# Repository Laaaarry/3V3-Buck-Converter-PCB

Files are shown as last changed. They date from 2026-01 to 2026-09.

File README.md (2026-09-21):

# 3V3 Buck Converter Project

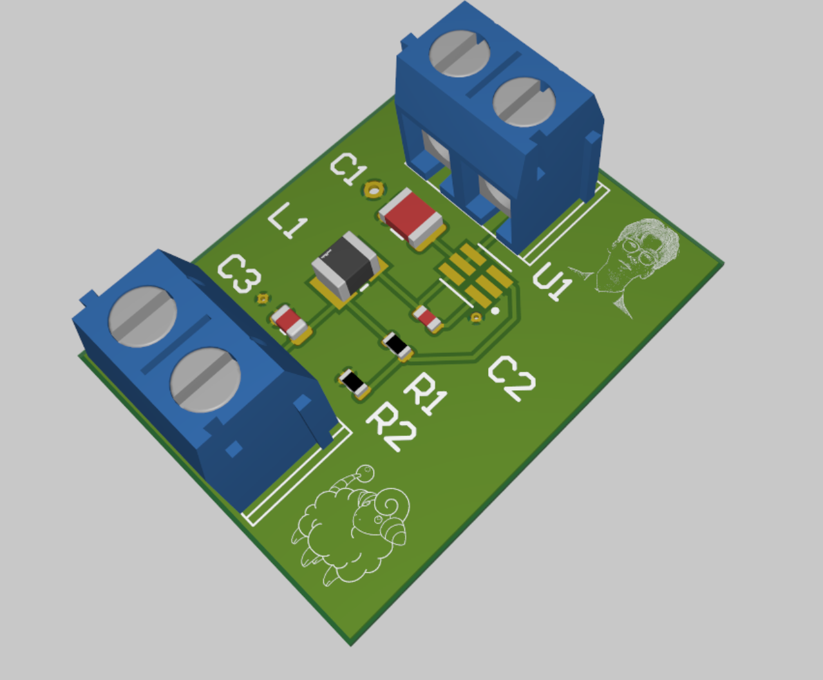
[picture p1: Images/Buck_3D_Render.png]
Board Render


Links:

**[Schematic + layout PDF](FAB-Lawrence_BuckConverter-A.1/Job1.PDF)**

**[BOM](FAB-Lawrence_BuckConverter-A.1/BOM/Lawrence_BuckConverter_BOM.xlsx)**

**[Fab package](FAB-Lawrence_BuckConverter-A.1/)**

## Overview
A 3V3 buck converter designed to take a higher voltage input and output 3.3 volts, with an output ripple voltage of under 100mV. 2-layer PCB with 9 components.
## Key Images

### Schematic Overview
Schematic of the 3V3 Buck converter. Uses a LMR50410 switcher.
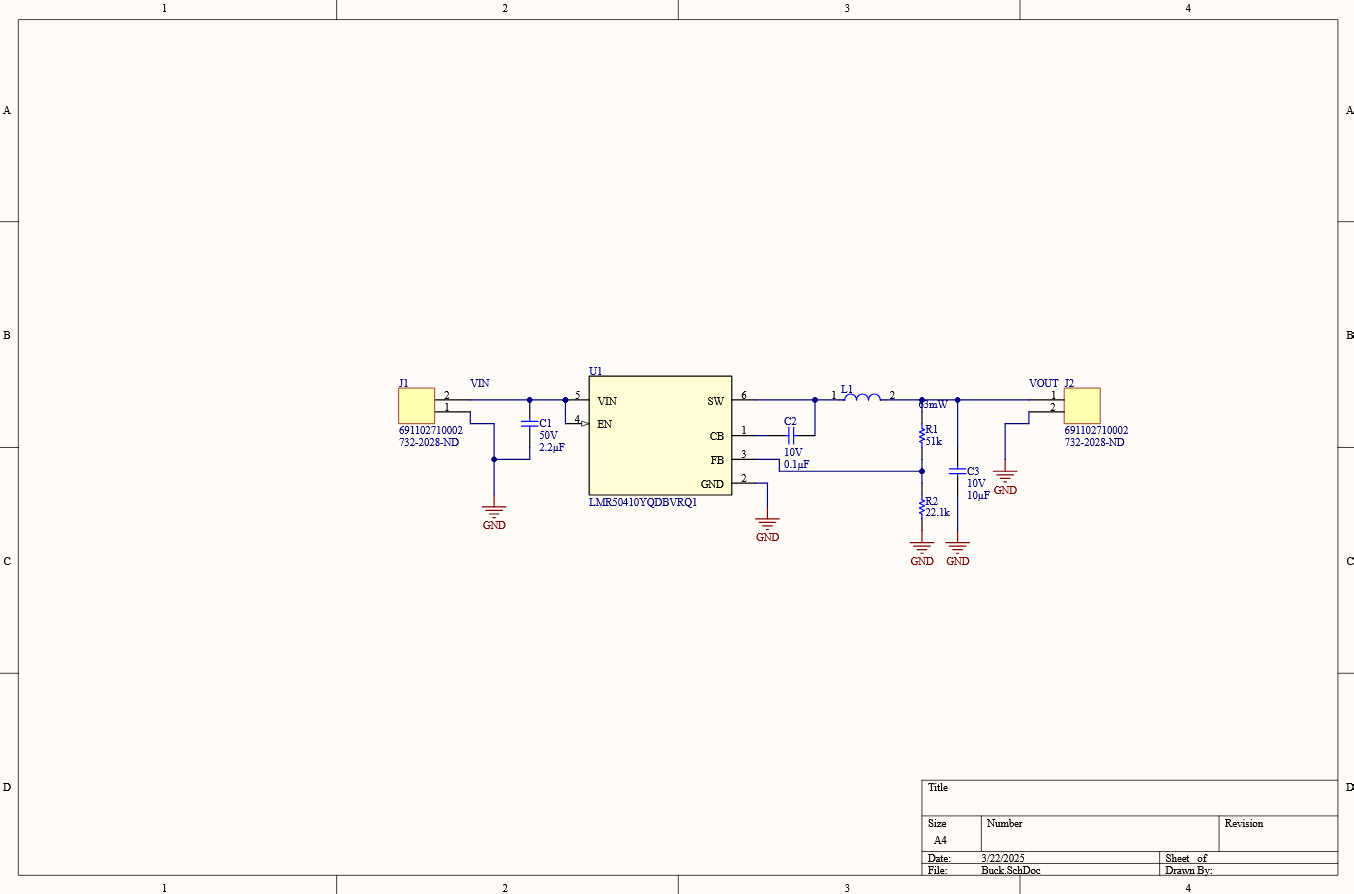
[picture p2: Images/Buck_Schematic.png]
Schematic Overview


### PCB Layout
This was the first ever PCB I made. I might have gone a little overboard on the line art.
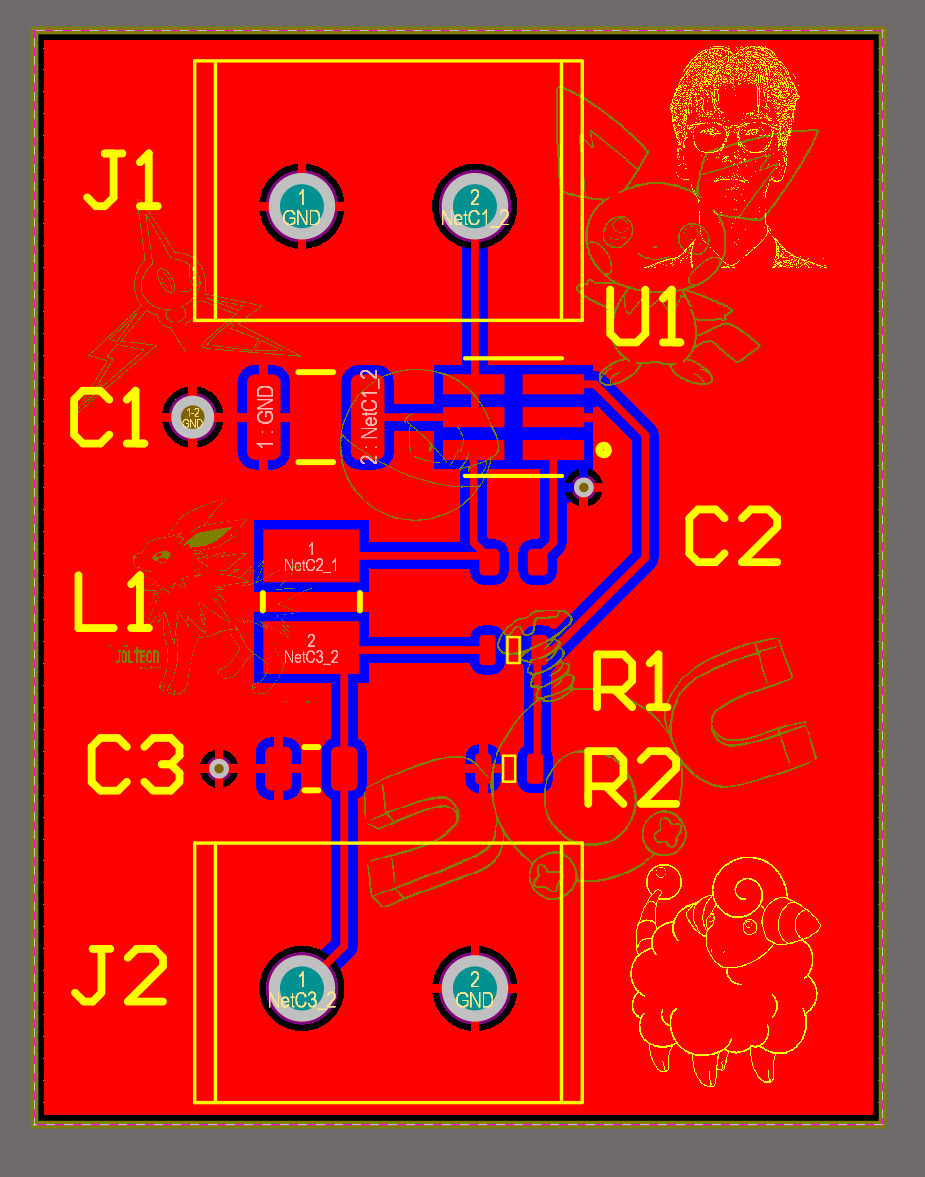
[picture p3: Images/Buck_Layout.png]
Layout


### Soldered PCB
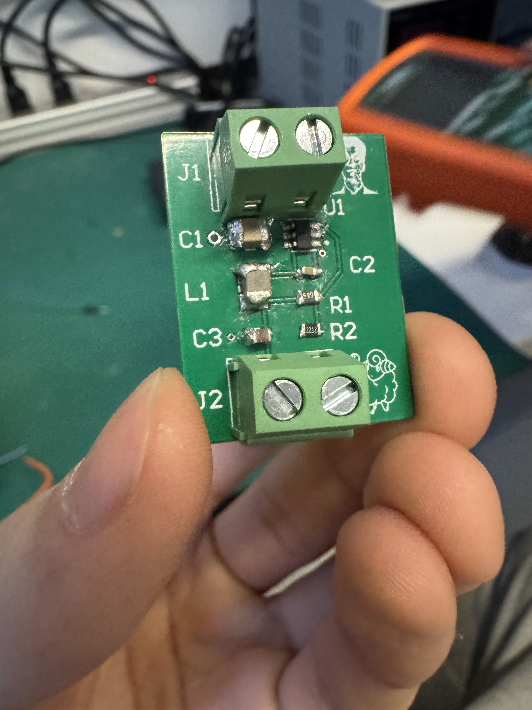
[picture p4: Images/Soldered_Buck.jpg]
Soldered


### Ripple Voltage Testing
As seen in the image, the buck converter meets the output ripple voltage requirement, with only 36mV Pk-Pk.
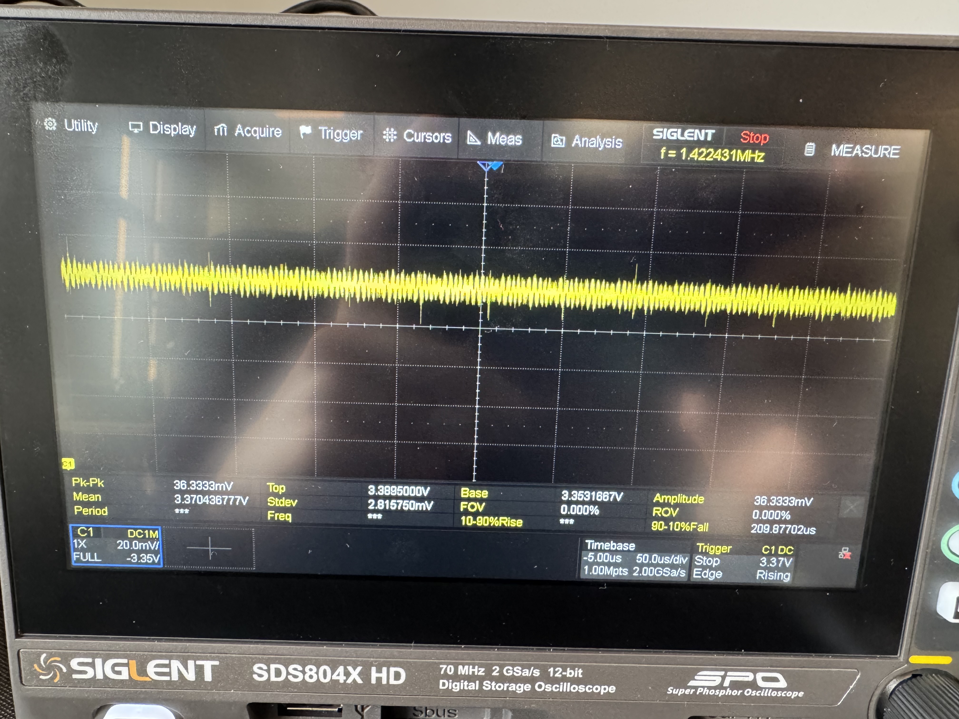
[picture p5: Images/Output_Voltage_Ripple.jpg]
ripple


### LTspice Ripple Voltage Simulation
I ran an LTspice simulation of the buck converter with a 5V input and then a 12V input to compare to what was measured. I used the only unencrypted [LMR50410 PSpice model](https://www.ti.com/product/LMR50410-Q1#design-tools-simulation) from the Texas Instruments website and converted it to work with LTspice, so it may not match the component properties perfectly.
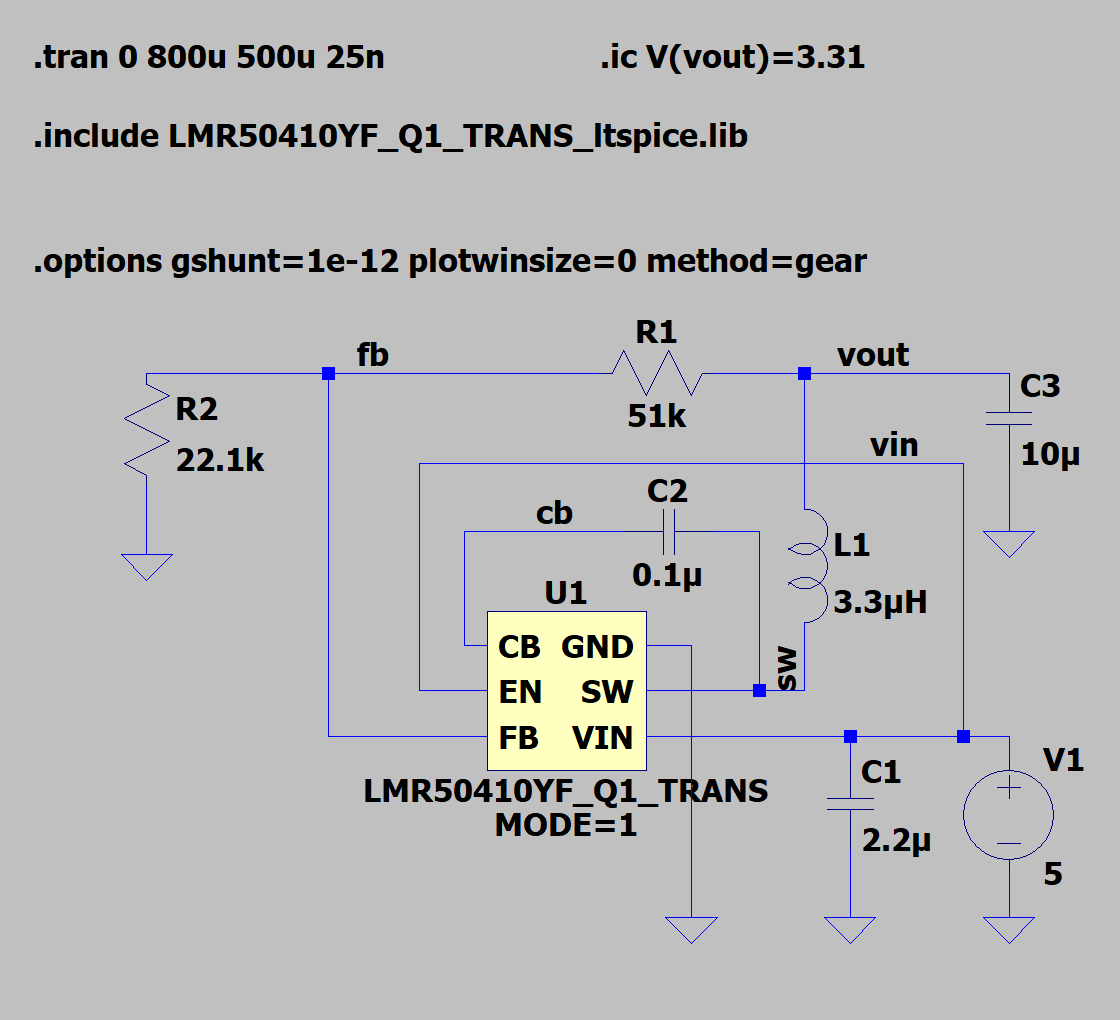
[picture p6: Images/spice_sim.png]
sim_screenshot


The 5V input simulation resulted in the following waveforms, with an output voltage ripple of around 0.99mV.
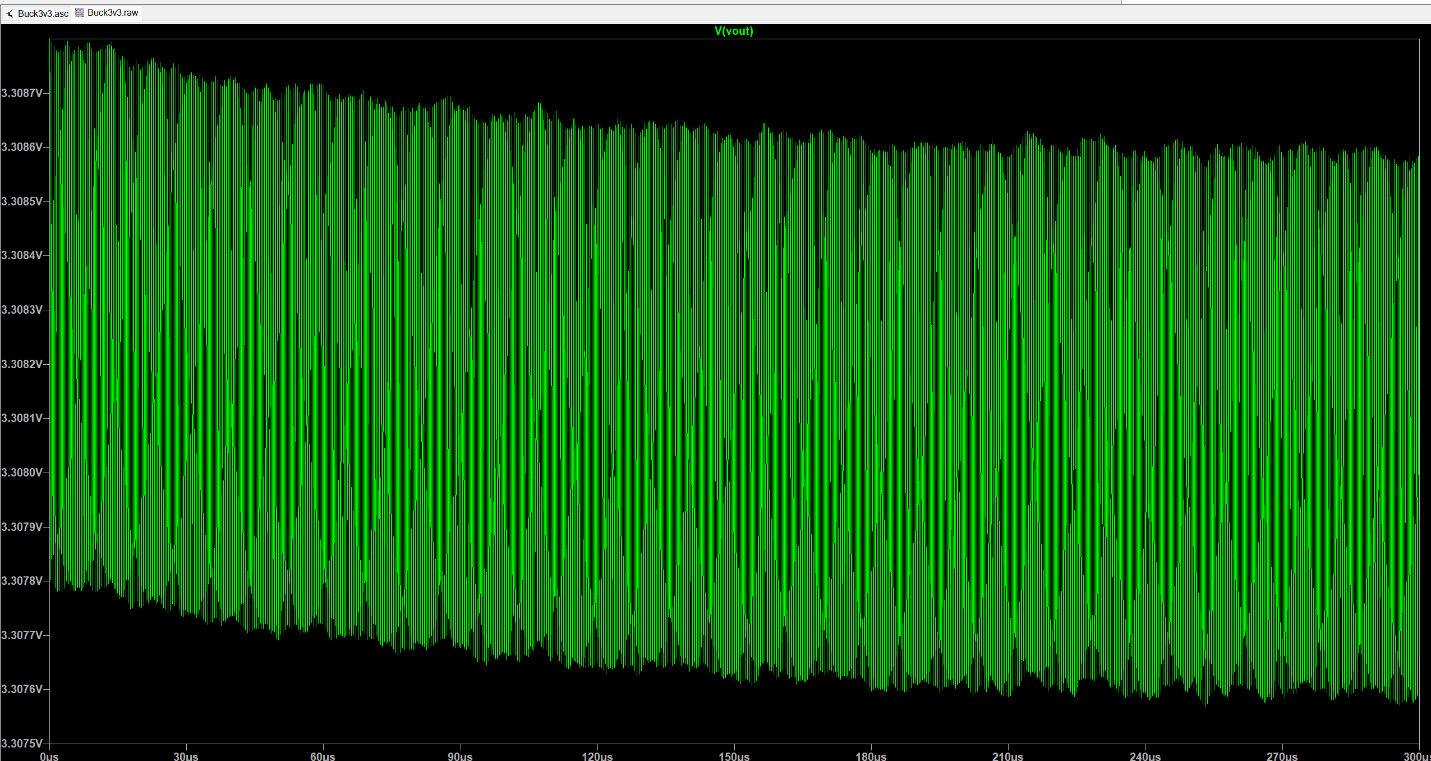
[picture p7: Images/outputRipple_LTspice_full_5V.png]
sim_ripple_full

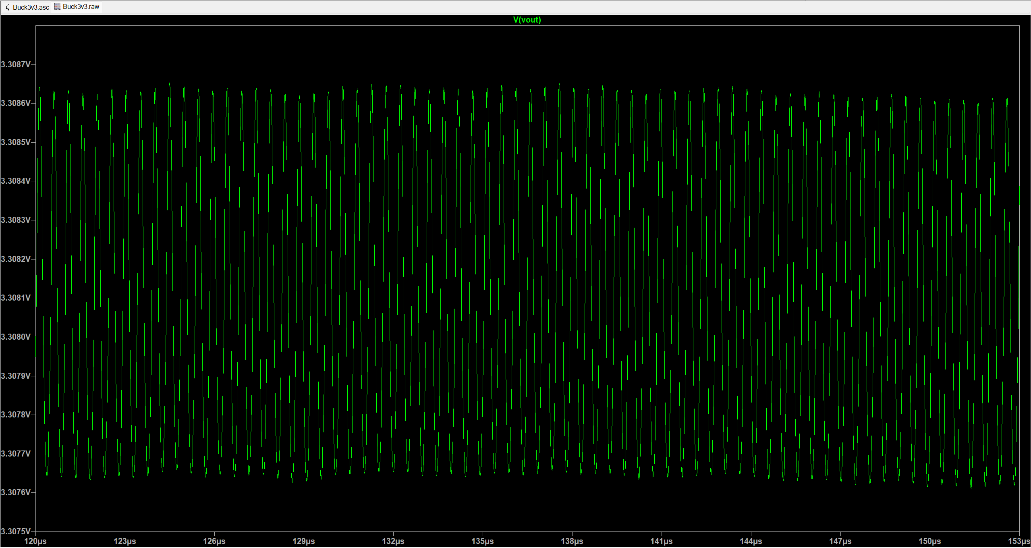
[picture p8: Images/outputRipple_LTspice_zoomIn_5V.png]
sim_ripple_zoomIn


The 12V input simulation resulted in the following waveforms, with an output voltage ripple of around 2.13mV
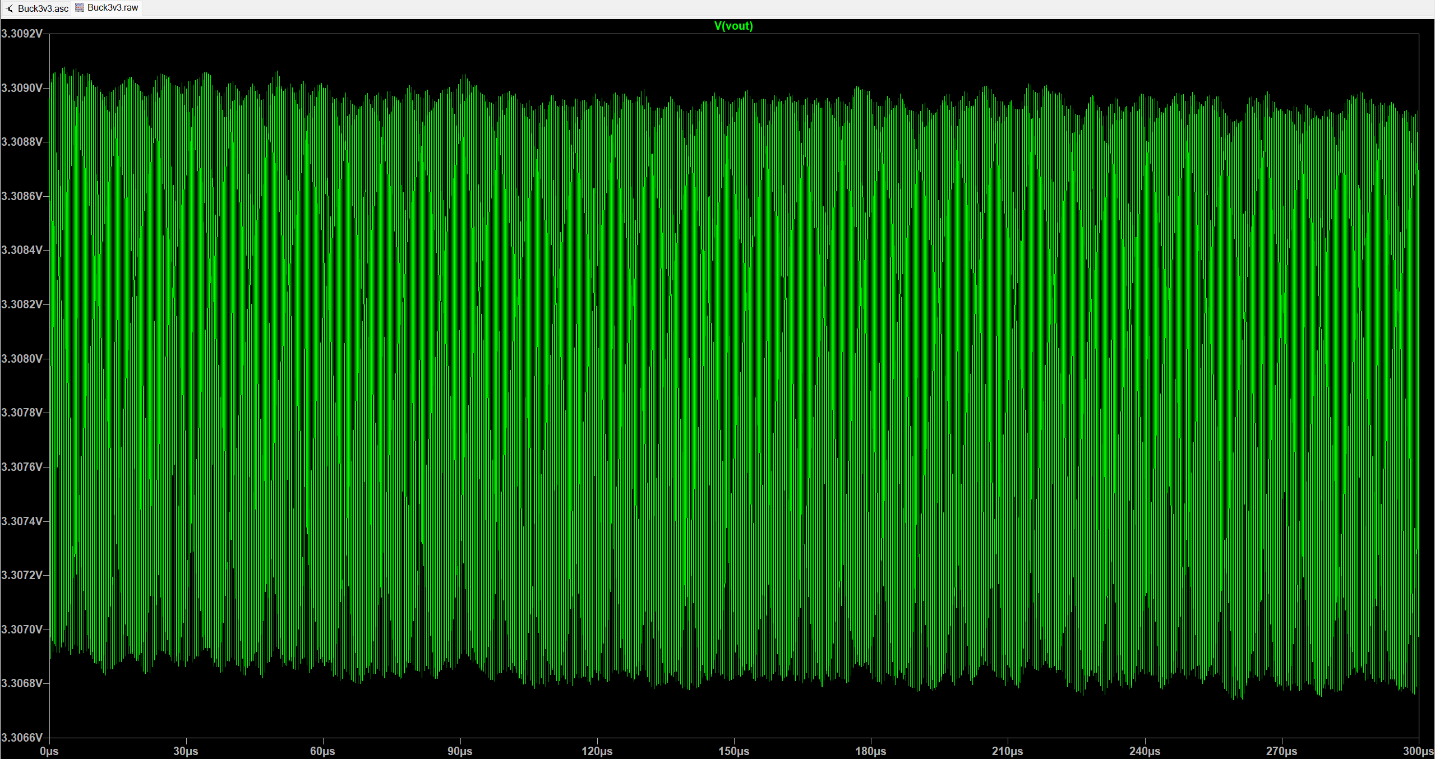
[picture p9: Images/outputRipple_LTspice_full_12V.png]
sim_ripple_full

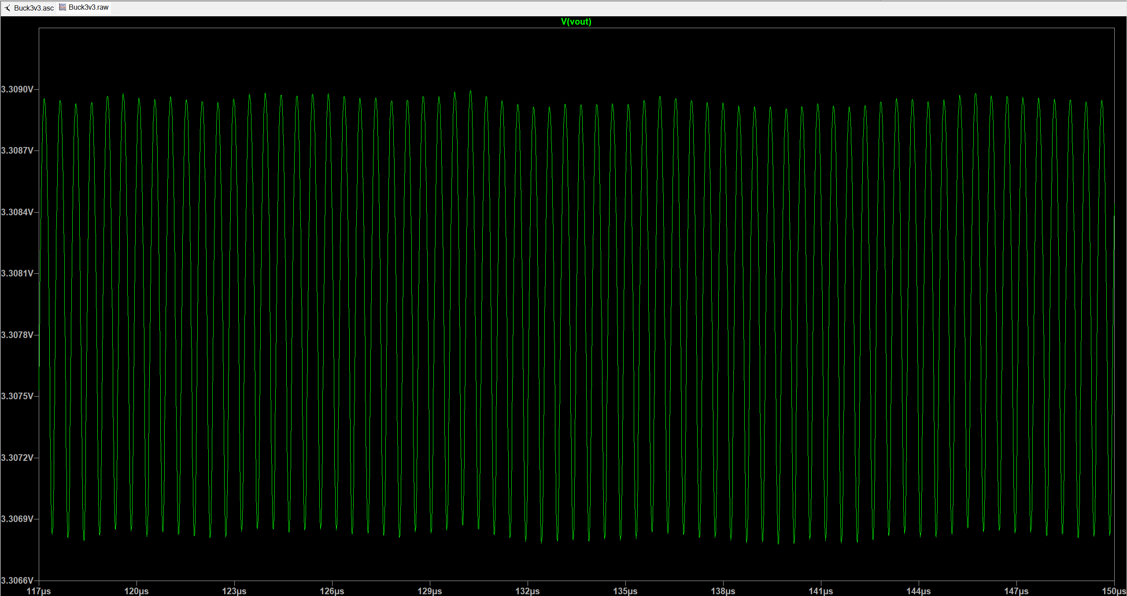
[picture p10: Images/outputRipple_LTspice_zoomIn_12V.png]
sim_ripple_zoomIn


These simulations show far lower output voltage ripple compared to the physical measurements. Potential causes for this discrepancy include ideal models for some components and the measurement noise.

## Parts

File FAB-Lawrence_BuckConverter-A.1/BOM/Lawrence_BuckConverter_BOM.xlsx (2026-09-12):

Comment | Description | Designator | Footprint | LibRef | Quantity
CGA6M3X7R1H225M200AB | CAP CER 2.2UF 50V X7R 1210 | C1 | CAP1210R | CMP-024-000534-5 | 1
LMK107BBJ106MAHT | CAP CER 10UF 10V X5R 0603 | C2 | CAP0603R | CMP-024-001218-5 | 1
GCM21BR71A106KE22L | CAP CER 10UF 10V X7R 0805 | C3 | CAP0805R | CMP-024-000714-5 | 1
691102710002 | 2 Position Wire to Board Terminal Block Horizontal with Board 0.197" (5.00mm) Through Hole | J1, J2 | CON2_SCREW_5.00MM_691102710002 | CMP-027-000000-1 | 2
DFE322520FD-3R3M=P2 | FIXED IND 3.3UH 2.3A 65 MOHM SMD | L1 | FP-DFE322520F_D-IPC_B | CMP-006-00002-2 | 1
Resistor 51k +/-5% 0402 63 mW | Chip Resistor, 51 KOhm, +/- 5%, 0.063 W, -55 to 155 degC, 0402 (1005 Metric) | R1 | RES0603R | CMP-054-001030-4 | 1
CRCW060322K1FKEA | RES SMD 22.1K OHM 1% 1/10W 0603 | R2 | RES0603R | CMP-054-001030-4 | 1
LMR50410YQDBVRQ1 | No Description Available | U1 | DBV0006A-IPC_A | LMR50410YQDBVRQ1 | 1

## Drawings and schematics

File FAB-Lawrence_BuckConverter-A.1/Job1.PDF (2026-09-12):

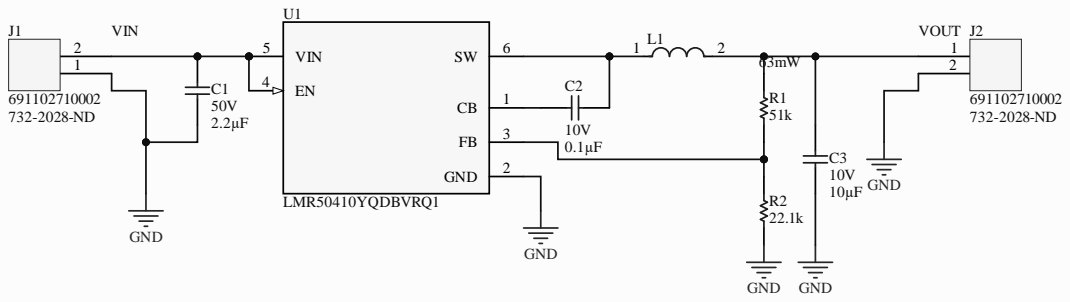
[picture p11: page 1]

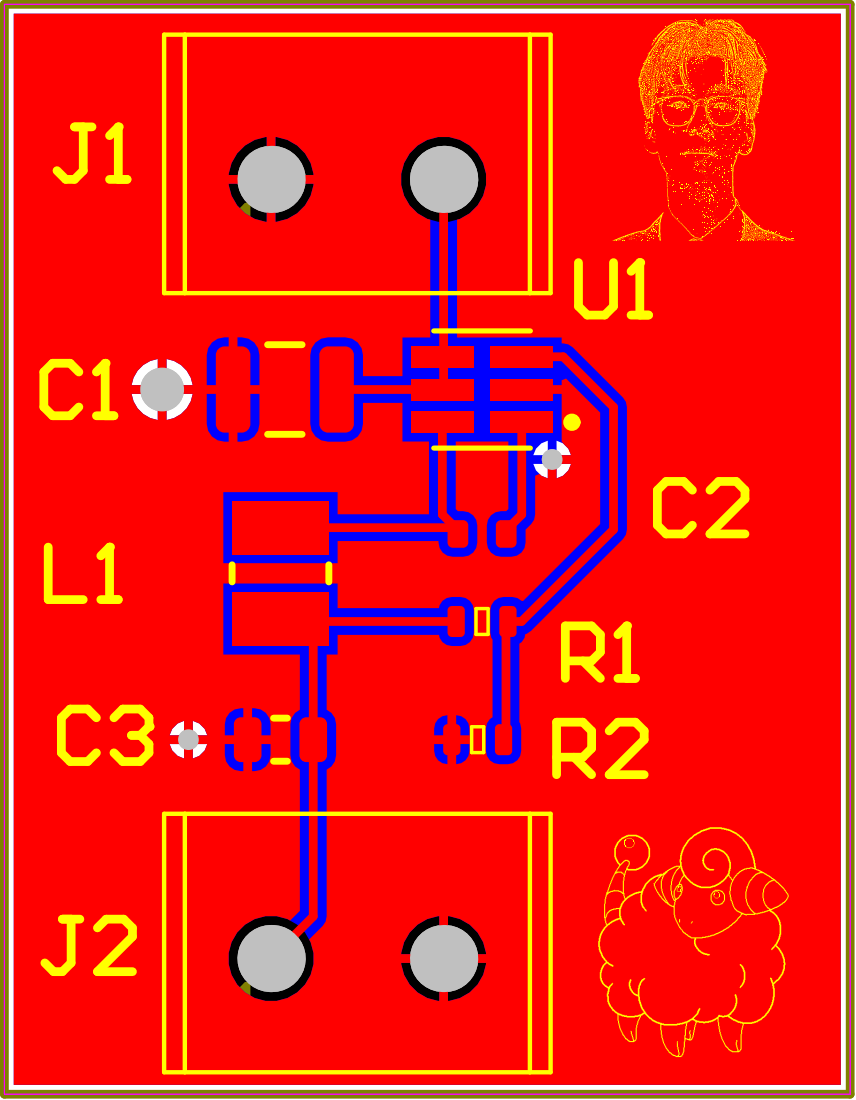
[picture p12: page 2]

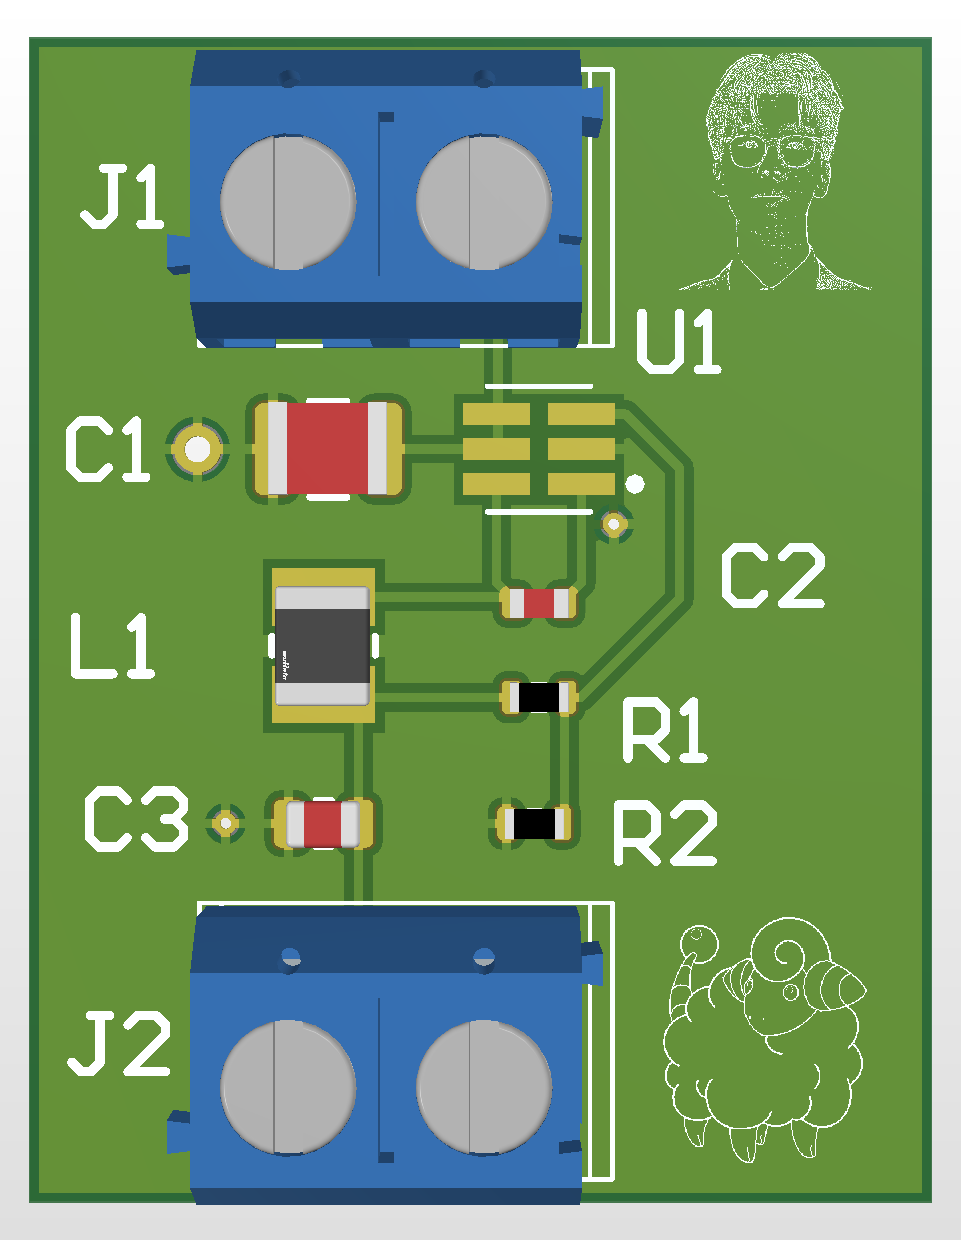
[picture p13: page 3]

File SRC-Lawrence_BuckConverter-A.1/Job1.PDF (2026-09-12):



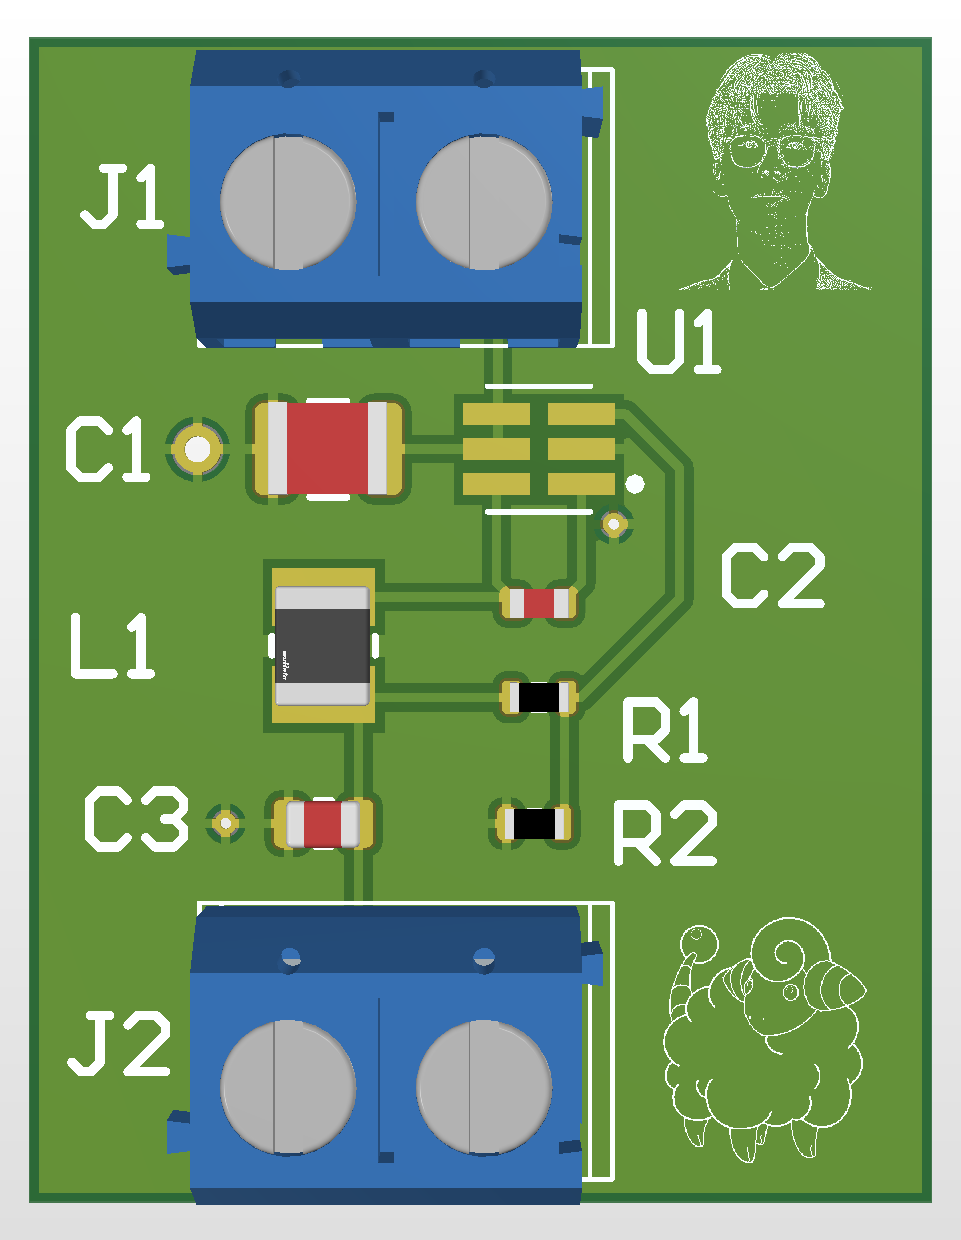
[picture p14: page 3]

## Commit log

2025-09-13 Commit of my buck converter project from UTAT Altium365
    [Buck.SchDoc, Lawrence_BuckConverter.PrjPcb, Schlib1.SchLib]
2026-02-02 images of schematic, layout, render
2026-02-02 Rename Soldered Buck.jpg to Soldered_Buck.jpg
    changing image names
2026-02-02 Rename Output Voltage Ripple.jpg to OutputVoltageRipple.jpg
2026-09-12 restructuring of repo and added fab files
    [Bill of Materials-Lawrence_BuckConverter.xlsx, Buck.PcbDoc, Buck.SchDoc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]
